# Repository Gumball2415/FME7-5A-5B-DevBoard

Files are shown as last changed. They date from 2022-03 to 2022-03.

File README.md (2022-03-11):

# FME7/S5A/S5B Development/Reproduction Cartridge Board

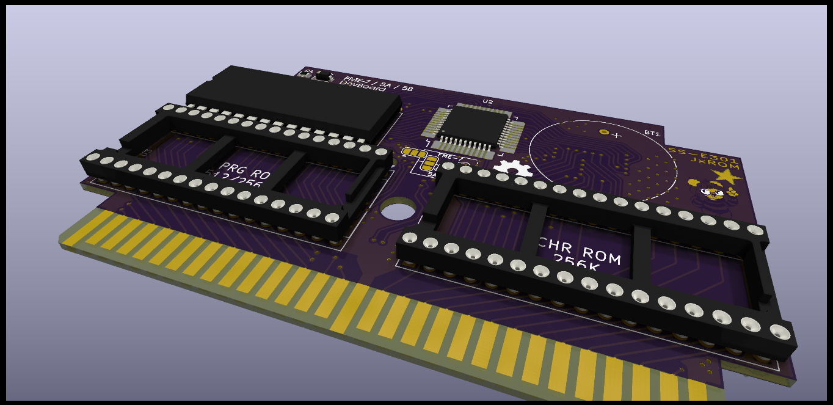
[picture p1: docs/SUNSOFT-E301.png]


An Open-Source HardWare (OSHW) development/reproduction cartridge PCB designed for INES mapper 69.

## PCB Specifications

Note that this project is optimized for JLCPCB manufacturing, so you may have to modify the gerber export, remove the "JLCJLCJLCJLC" silkscreen text, etc.

- 2 layers
- 92mm x 56.7mm
- 1.20mm thickness
- ENIG-RoHS surface finish recommended; Gold fingers optional
- Light silkscreen, dark soldermask

## License

The PCB and schematics are licensed under the TAPR Open Hardware License ([www.tapr.org/OHL](http://www.tapr.org/OHL)). © Persune 2021

## Credits

- Lockster - Help and assistance with schematics
- lidnariq - Clarification on FME7 connections
- yoeynsf - Pixel art of Dagga
- plgDavid - Inspiration
- Special thanks to the NESDEV community, this project wouldn't have been possible without their extensive help and wiki.

## Support

Support me on [Ko-Fi](https://ko-fi.com/persune) to help me afford hardware development equipment and further improve this project!

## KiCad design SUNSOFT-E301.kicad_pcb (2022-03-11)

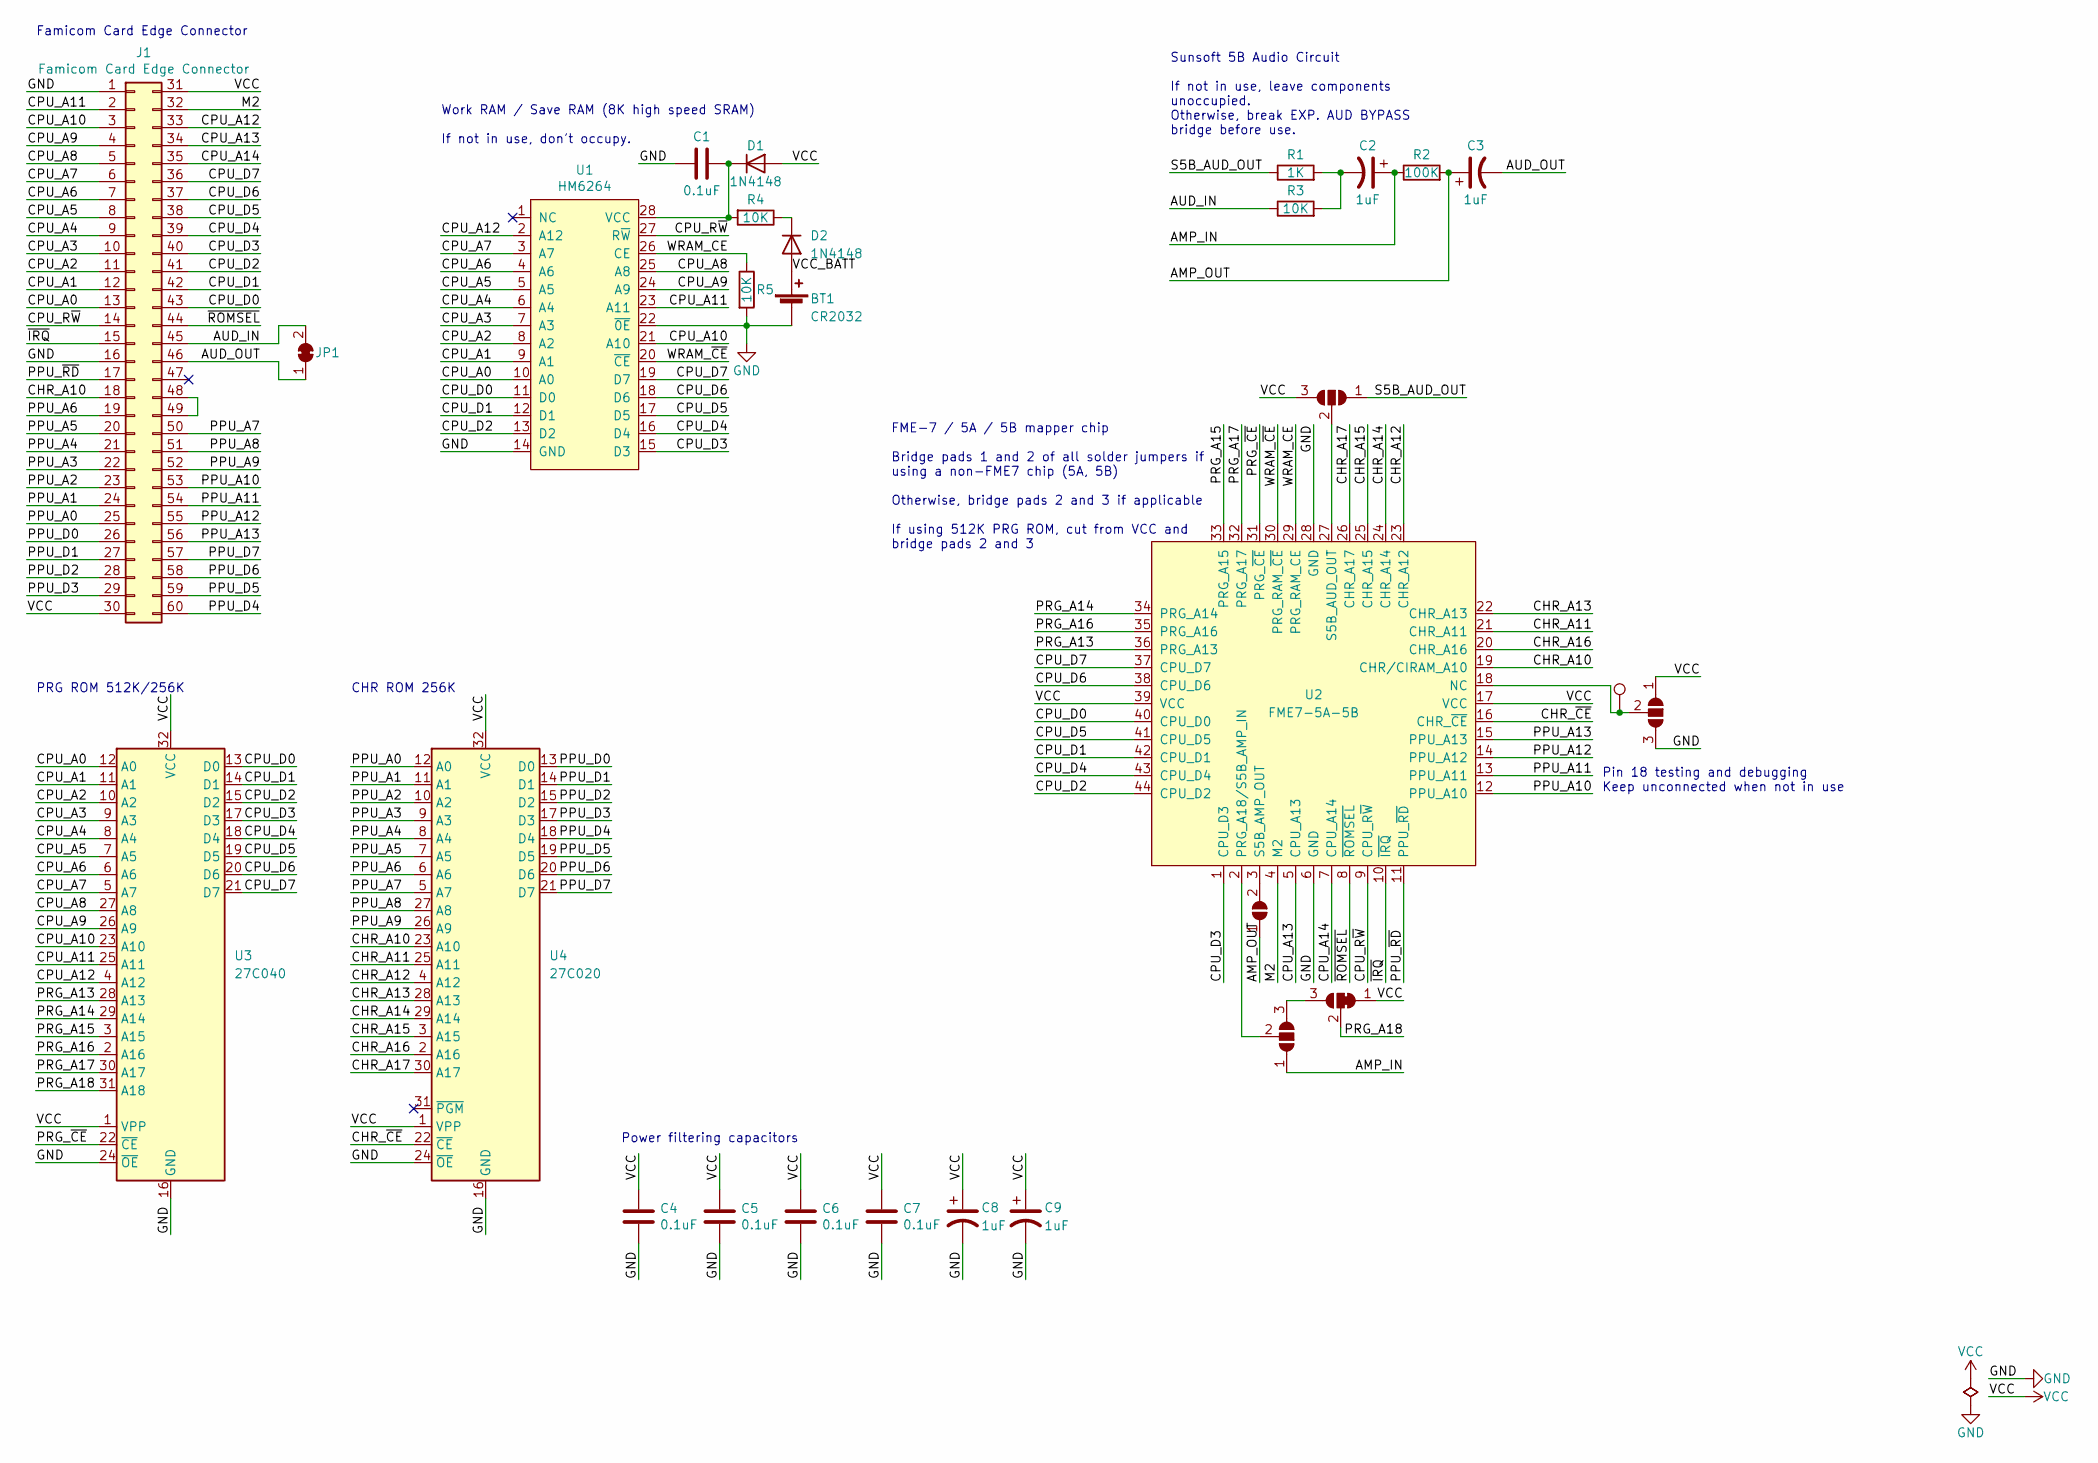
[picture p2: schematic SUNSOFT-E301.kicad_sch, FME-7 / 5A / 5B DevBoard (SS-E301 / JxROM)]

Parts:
BT1: CR2032; BS-02-A1AK006; LCSC C964746
C1, C4, C5, C6, C7: 0.1uF; C_0805_2012Metric; LCSC C779984
C2, C3, C8, C9: 1uF; CP_Elec_4x5.3; LCSC C249445
D1, D2: 1N4148; D_SOD-123; LCSC C2099
J1: Famicom Card Edge Connector; BBW-E301
JP1: SolderJumper_2_Bridged; SolderJumper-2_P1.3mm_Bridged_RoundedPad1.0x1.5mm
JP2, JP4, JP5: SolderJumper-3_P1.3mm_Open_RoundedPad1.0x1.5mm
JP3: SolderJumper-2_P1.3mm_Open_RoundedPad1.0x1.5mm
JP6: SolderJumper-3_P1.3mm_Bridged12_RoundedPad1.0x1.5mm
R1: 1K; R_0805_2012Metric; LCSC C441949
R2: 100K; R_0805_2012Metric; LCSC C441960
R3, R4, R5: 10K; R_0805_2012Metric; LCSC C441955
TP1: TestPoint_Pad_D1.0mm
U1: HM6264; DIP-28_W15.24mm; LCSC C72121
U2: FME7-5A-5B; Sunsoft-5
U3: 27C040; DIP-32_W15.24mm_Socket; LCSC C72122
U4: 27C020; DIP-32_W15.24mm_Socket; LCSC C72122

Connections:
/AMP_IN: C2.1, JP2.1 (A), R2.1
/AMP_OUT: C3.1, JP3.1 (A), R2.2
/AUD_IN: J1.45, JP1.2 (B), R3.1
/AUD_OUT: C3.2, J1.46, JP1.1 (A)
/CHR_A10: J1.18, U2.19 (CHR/CIRAM_A10), U4.23 (A10)
/CHR_A11: U2.21 (CHR_A11), U4.25 (A11)
/CHR_A12: U2.23 (CHR_A12), U4.4 (A12)
/CHR_A13: U2.22 (CHR_A13), U4.28 (A13)
/CHR_A14: U2.24 (CHR_A14), U4.29 (A14)
/CHR_A15: U2.25 (CHR_A15), U4.3 (A15)
/CHR_A16: U2.20 (CHR_A16), U4.2 (A16)
/CHR_A17: U2.26 (CHR_A17), U4.30 (A17)
/CHR_~CE: U2.16 (CHR_~CE), U4.22 (~CE)
/CPU_A0: J1.13, U1.10 (A0), U3.12 (A0)
/CPU_A1: J1.12, U1.9 (A1), U3.11 (A1)
/CPU_A2: J1.11, U1.8 (A2), U3.10 (A2)
/CPU_A3: J1.10, U1.7 (A3), U3.9 (A3)
/CPU_A4: J1.9, U1.6 (A4), U3.8 (A4)
/CPU_A5: J1.8, U1.5 (A5), U3.7 (A5)
/CPU_A6: J1.7, U1.4 (A6), U3.6 (A6)
/CPU_A7: J1.6, U1.3 (A7), U3.5 (A7)
/CPU_A8: J1.5, U1.25 (A8), U3.27 (A8)
/CPU_A9: J1.4, U1.24 (A9), U3.26 (A9)
/CPU_A10: J1.3, U1.21 (A10), U3.23 (A10)
/CPU_A11: J1.2, U1.23 (A11), U3.25 (A11)
/CPU_A12: J1.33, U1.2 (A12), U3.4 (A12)
/CPU_A13: J1.34, U2.5 (CPU_A13)
/CPU_A14: J1.35, U2.7 (CPU_A14)
/CPU_D0: J1.43, U1.11 (D0), U2.40 (CPU_D0), U3.13 (D0)
/CPU_D1: J1.42, U1.12 (D1), U2.42 (CPU_D1), U3.14 (D1)
/CPU_D2: J1.41, U1.13 (D2), U2.44 (CPU_D2), U3.15 (D2)
/CPU_D3: J1.40, U1.15 (D3), U2.1 (CPU_D3), U3.17 (D3)
/CPU_D4: J1.39, U1.16 (D4), U2.43 (CPU_D4), U3.18 (D4)
/CPU_D5: J1.38, U1.17 (D5), U2.41 (CPU_D5), U3.19 (D5)
/CPU_D6: J1.37, U1.18 (D6), U2.38 (CPU_D6), U3.20 (D6)
/CPU_D7: J1.36, U1.19 (D7), U2.37 (CPU_D7), U3.21 (D7)
/CPU_R~W: J1.14, U1.27 (R~W), U2.9 (CPU_R~W)
/M2: J1.32, U2.4 (M2)
/PPU_A0: J1.25, U4.12 (A0)
/PPU_A1: J1.24, U4.11 (A1)
/PPU_A2: J1.23, U4.10 (A2)
/PPU_A3: J1.22, U4.9 (A3)
/PPU_A4: J1.21, U4.8 (A4)
/PPU_A5: J1.20, U4.7 (A5)
/PPU_A6: J1.19, U4.6 (A6)
/PPU_A7: J1.50, U4.5 (A7)
/PPU_A8: J1.51, U4.27 (A8)
/PPU_A9: J1.52, U4.26 (A9)
/PPU_A10: J1.53, U2.12 (PPU_A10)
/PPU_A11: J1.54, U2.13 (PPU_A11)
/PPU_A12: J1.55, U2.14 (PPU_A12)
/PPU_A13: J1.56, U2.15 (PPU_A13)
/PPU_D0: J1.26, U4.13 (D0)
/PPU_D1: J1.27, U4.14 (D1)
/PPU_D2: J1.28, U4.15 (D2)
/PPU_D3: J1.29, U4.17 (D3)
/PPU_D4: J1.60, U4.18 (D4)
/PPU_D5: J1.59, U4.19 (D5)
/PPU_D6: J1.58, U4.20 (D6)
/PPU_D7: J1.57, U4.21 (D7)
/PPU_~RD: J1.17, U2.11 (PPU_~RD)
/PRG_A13: U2.36 (PRG_A13), U3.28 (A13)
/PRG_A14: U2.34 (PRG_A14), U3.29 (A14)
/PRG_A15: U2.33 (PRG_A15), U3.3 (A15)
/PRG_A16: U2.35 (PRG_A16), U3.2 (A16)
/PRG_A17: U2.32 (PRG_A17), U3.30 (A17)
/PRG_A18: JP6.2 (C), U3.31 (A18)
/PRG_~CE: U2.31 (PRG_~CE), U3.22 (~CE)
/S5B_AUD_OUT: JP4.1 (A), R1.1
/VCC_BATT: BT1.1 (+), D2.2 (A)
/WRAM_CE: R5.1, U1.26 (CE), U2.29 (PRG_RAM_CE)
/WRAM_~CE: U1.20 (~CE), U2.30 (PRG_RAM_~CE)
/~IRQ: J1.15, U2.10 (~IRQ)
/~ROMSEL: J1.44, U2.8 (~ROMSEL)
GND: BT1.2 (-), C1.1, C4.2, C5.2, C6.2, C7.2, C8.2, C9.2, J1.1, J1.16, JP5.3 (B), R5.2, U1.14 (GND), U1.22 (~0E), U2.6 (GND), U2.28 (GND), U3.16 (GND), U3.24 (~OE), U4.16 (GND), U4.24 (~OE)
unnamed: C1.2, D1.1 (K), R4.2, U1.28 (VCC)
unnamed: C2.2, R1.2, R3.2
unnamed: D2.1 (K), R4.1
unnamed: J1.48, J1.49
unnamed: JP2.2 (C), U2.2 (PRG_A18/S5B_AMP_IN)
unnamed: JP2.3 (B), JP6.3 (B)
unnamed: JP3.2 (B), U2.3 (S5B_AMP_OUT)
unnamed: JP4.2 (C), U2.27 (S5B_AUD_OUT)
unnamed: JP5.2 (C), TP1.1, U2.18 (NC)
VCC: C4.1, C5.1, C6.1, C7.1, C8.1, C9.1, D1.2 (A), J1.30, J1.31, JP4.3 (B), JP5.1 (A), JP6.1 (A), U2.17 (VCC), U2.39 (VCC), U3.1 (VPP), U3.32 (VCC), U4.1 (VPP), U4.32 (VCC)

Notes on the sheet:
Sunsoft 5B Audio Circuit If not in use, leave components unoccupied. Otherwise, break EXP. AUD BYPASS bridge before use.
Power filtering capacitors
Famicom Card Edge Connector
CHR ROM 256K
FME-7 / 5A / 5B mapper chip Bridge pads 1 and 2 of all solder jumpers if using a non-FME7 chip (5A, 5B) Otherwise, bridge pads 2 and 3 if applicable If using 512K PRG ROM, cut from VCC and bridge pads 2 and 3
Work RAM / Save RAM (8K high speed SRAM) If not in use, don't occupy.
Pin 18 testing and debugging Keep unconnected when not in use
PRG ROM 512K/256K

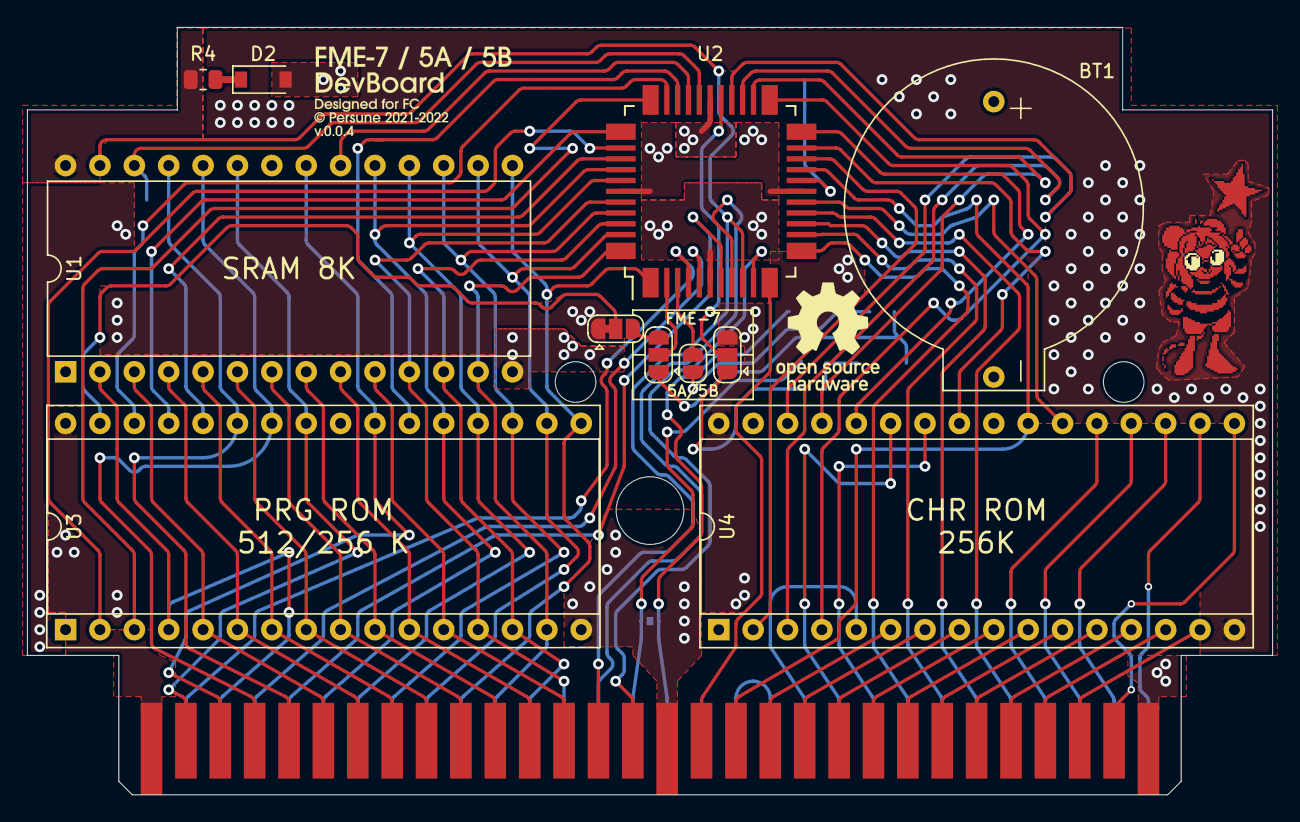
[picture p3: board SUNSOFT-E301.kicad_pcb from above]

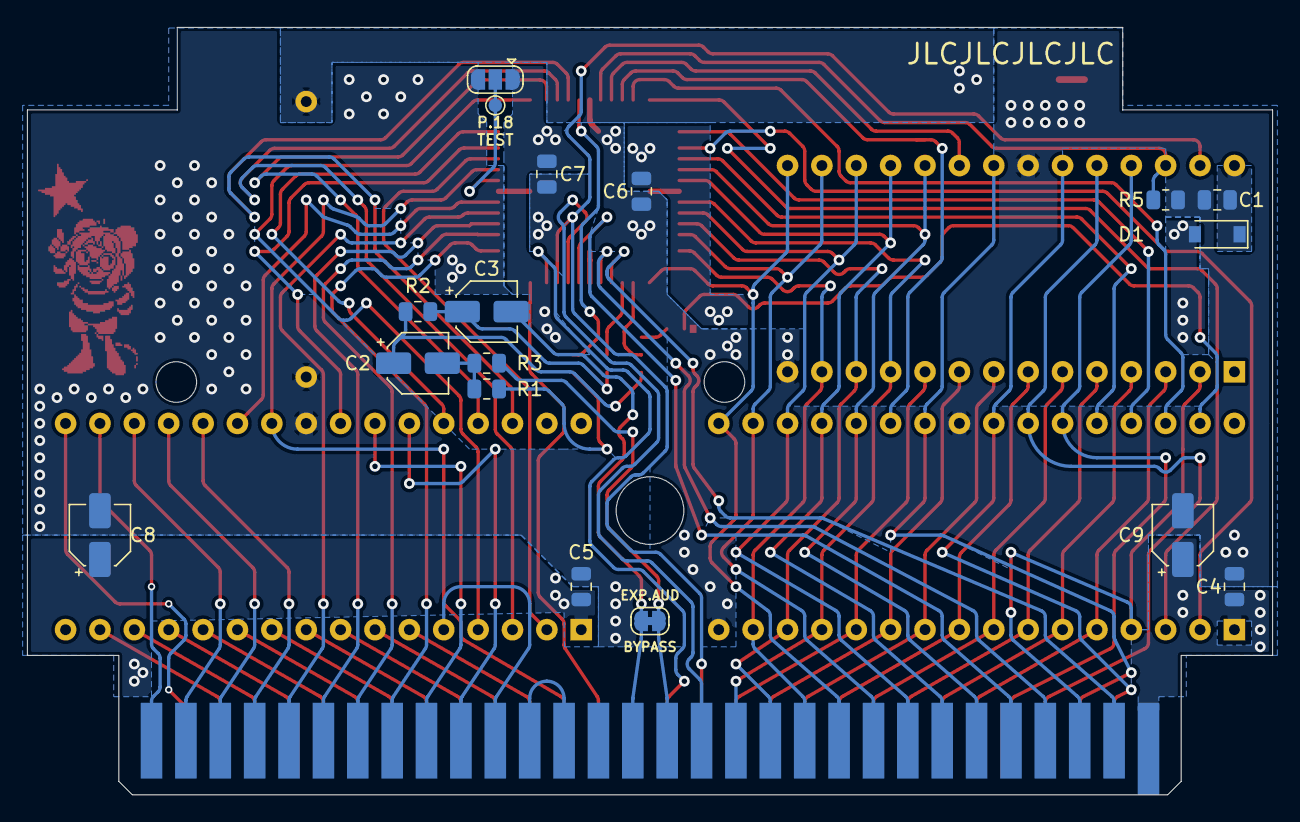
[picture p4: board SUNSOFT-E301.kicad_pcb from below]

Board: 2 copper layers, 92.0 x 56.7 mm, 30 parts (17 on the bottom side), 85 nets.

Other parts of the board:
Ref**: Val**; art_front

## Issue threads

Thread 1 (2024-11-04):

Gimmick with kazzo,Famicom to test the gray screen

Cyrus331, 2024-11-04:
After burning Gimmick with kazzo, I went to Famicom to test the gray screen. Please help me find out the reason. I used a 5B chip. I disconnected the VCC of PRGA18 and the AUD BYPASSbridge. Is the chip used by PRG and CHR ROM wrong?
This is the burning script
[sunsoft_fme.zip](https://github.com/user-attachments/files/17619611/sunsoft_fme.zip)

Cyrus331, 2024-11-04:
![Uploading 微信图片_20241104223159.jpg…]()
![Uploading 微信图片_20241104223217.jpg…]()

Cyrus331, 2024-11-04:
![Uploading font.jpg…]()
![Uploading back.jpg…]()

Gumball2415, 2024-11-04:
hello, i haven't touched this project in a while.

i may continue at a future time, but for now this is in limbo.

the issue with the board are incorrect pinouts, especially the flash ROMs used
(some flash ROMs has a slightly different pinout than what this project used, for example SST39SF040).

as a temporary solution, you may need to lift pins and reconnect, though i'm not sure if this is enough to alleviate the issues.

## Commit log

2021-12-08 Add PCB specifications
2021-12-11 Revision 0.0.2
    - connect CIRAM A10
    - improve plane distribution
    [SUNSOFT-E301.kicad_pcb, SUNSOFT-E301.sch]
2021-12-17 Revision 0.0.3
    - updated outline to match Barcode World
    - added pixel sprite art by @yoeynsf
    [SUNSOFT-E301.kicad_pcb, SUNSOFT-E301.sch]
2021-12-27 KiCad 6.0
    [SUNSOFT-E301.kicad_pcb, SUNSOFT-E301.kicad_sch]
2022-03-11 Revision 0.0.4
    [SUNSOFT-E301.kicad_pcb, SUNSOFT-E301.kicad_sch]
